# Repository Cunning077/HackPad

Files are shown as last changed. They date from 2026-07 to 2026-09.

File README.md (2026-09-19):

# Oled Display Hackpad

A differing design hackpad allowing customization at a cost effective way, complete with an advanced event handler and a system that makes use of computer hardware to perform complicated tasks on a budget microcontroller.

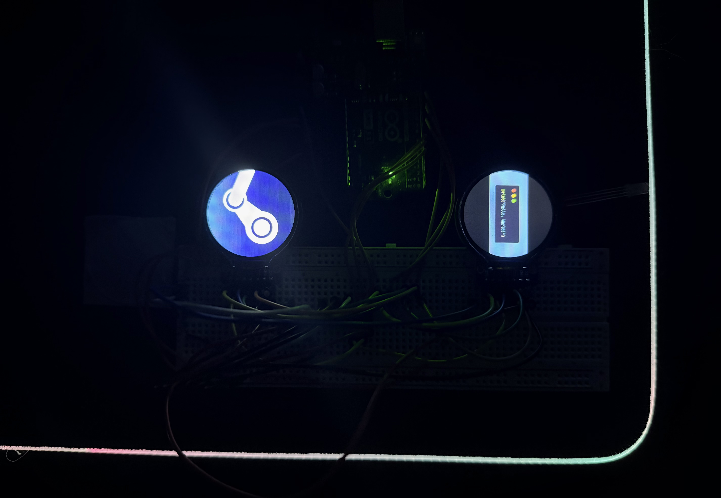
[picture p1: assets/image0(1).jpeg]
Prototype Screens


## Features

 - 1.28 " TFT Display (no specified number)
 - Customizable Macro Keys
 - Plug And Play USB Communication
 - User-Expandable Actions 

## Cad
The hackpad comes in 3 pieces, the PCB, the top case, and the bottom, the pcb is fastened into the bottom through 5 rectangular blocks that screw into the sides of the bottom section case, the top and bottom are fastened together with 4 screws.
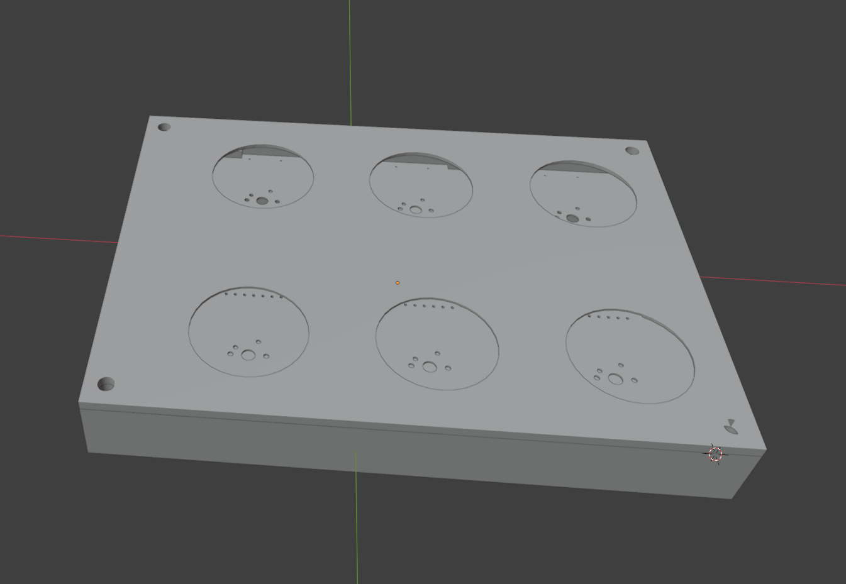
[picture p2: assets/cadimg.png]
Cad Image

(No current design for the case as in cosmetic look, if its popular maybe i will do one)

## PCB
Pcb made in kicad
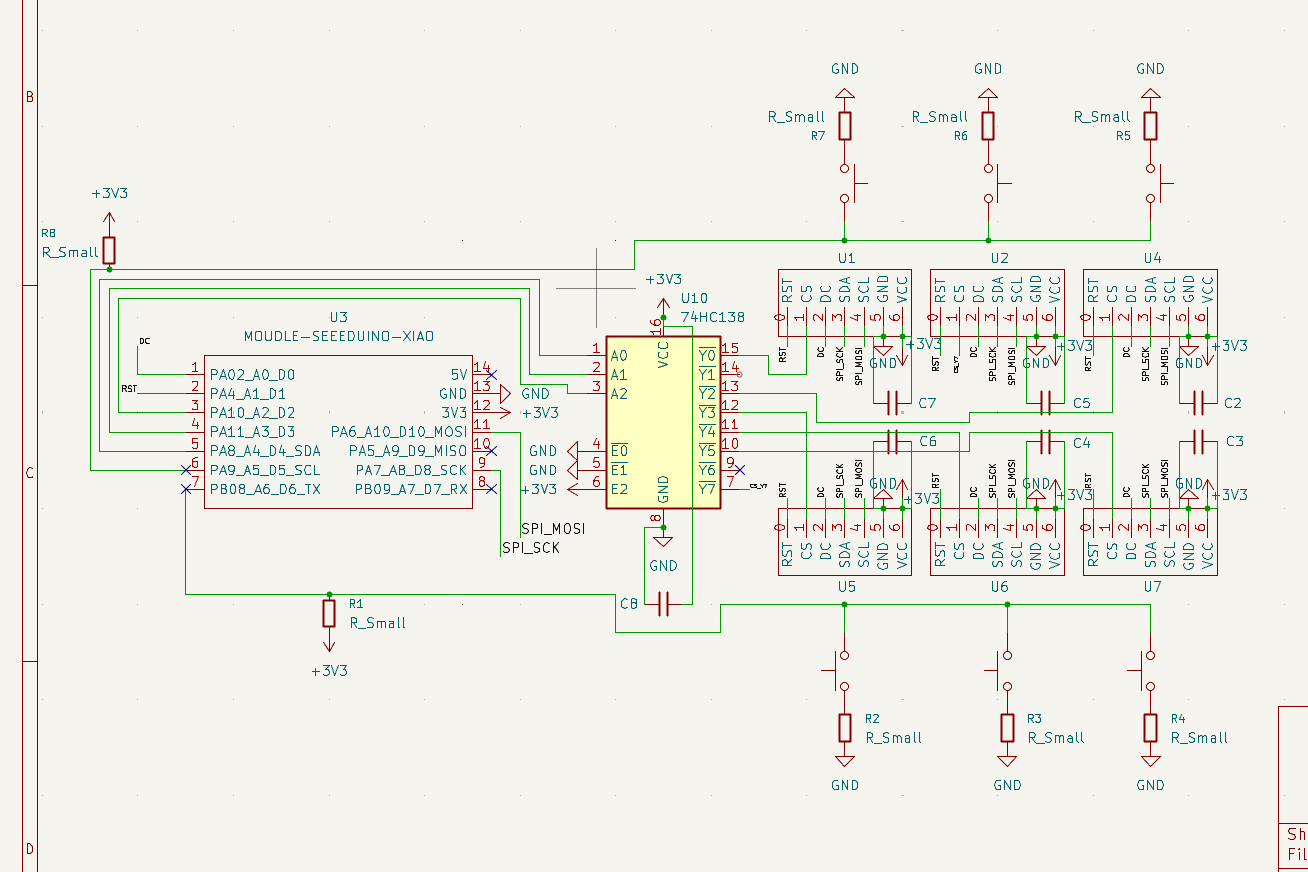
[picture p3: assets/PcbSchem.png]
Schematic

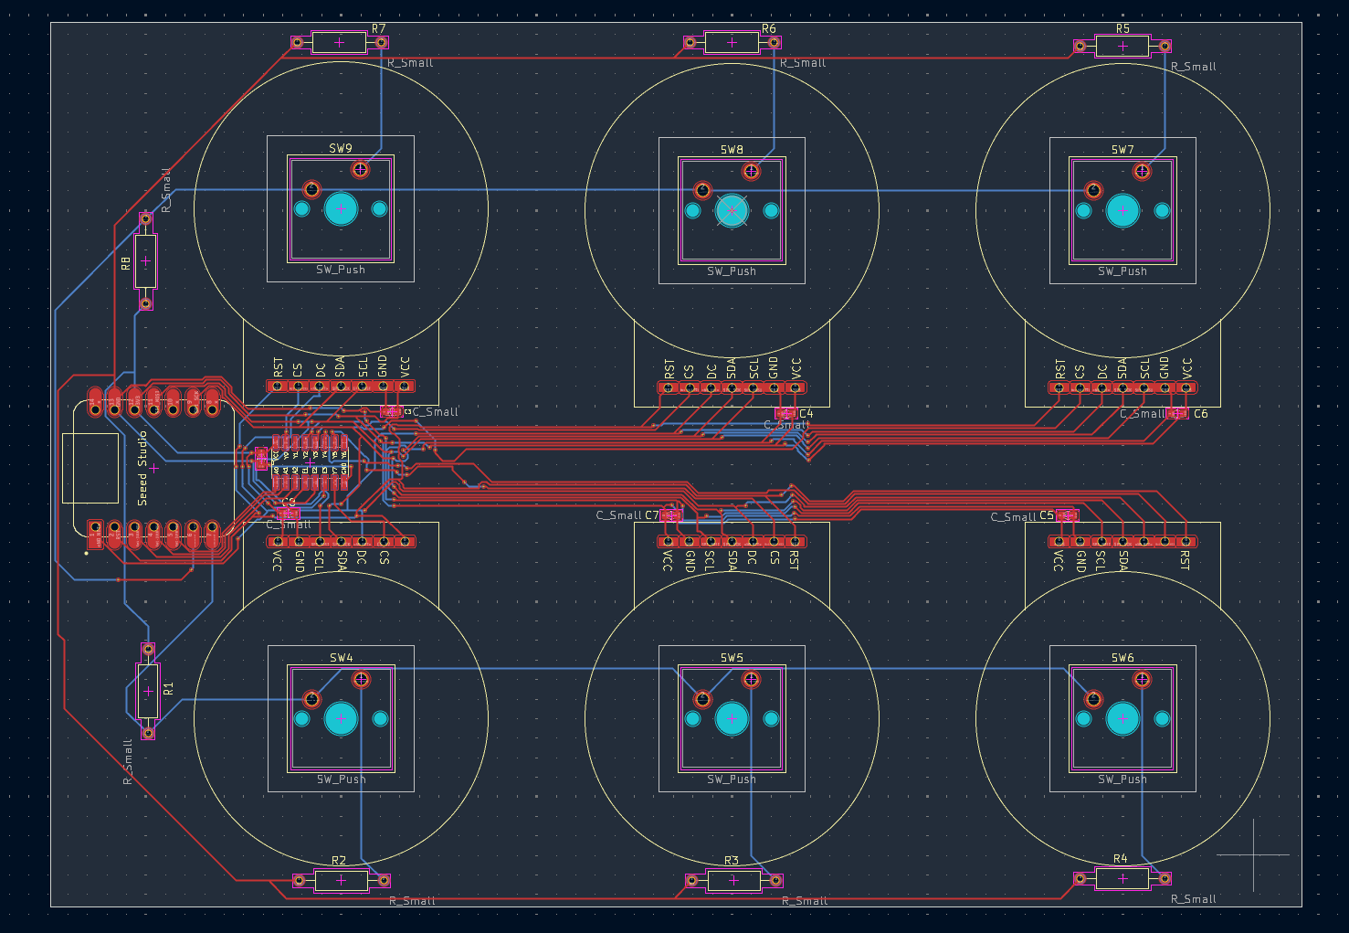
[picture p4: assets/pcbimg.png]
Pcb Image


## Firmware + Software
Software is broken down into the macro boards logic and the communication/event handler on the pc side. To get both simply clone this git hub repo, install platformio, and run the upload command for the arduinos logic. While the pc is abit trickier depending on what operating system you use. For Linux mint simply set the deamon/service.py as a startup service, it will simply run in the background searching for the macro board. The deamon is designed to simply run of that single service file, later on if this is popular i will add contribution info and other important stuff to allow others to more deeply control the board.

## BOM

 - 6 Cherry MX Switch
 - 6 1.28" TFT Displays
 -  4 * 4.5mm outer diameter 6mm depth heat inserts
 -  5 * 4.5mm outer diameter 4 mm depth heat inserts
 -  Screws that match (i got hundreds idk the name)
 - 2 sets of 3 differing resistors
 - 74HC138 circuit board
 - Microcontroller of choice 
 - 2 printed parts + 5 rectangular bits

|  Part| Price | Quantity |
|--|--|--|
|XIAO Seed Studio|$5.40|1|
|1.28 TFT Display|$6.00|6|
|4.5mm outer 6mm depth heat insert| $0.03|4|
|4.5mm outer 4mm depth heat insert|$0.03|5|
|Resistor set|$10.00|1|
|74HC138 circuit|$3.00|1|
|Cherry MX Switch|$0.5|6|
|Total|$48.67|Null|

See https://stardance.hackclub.com/projects/10218/devlogs/11779 for a detailed construction of the circuit on a bread board.

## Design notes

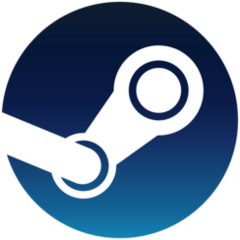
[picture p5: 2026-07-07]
deamon/images/DISP0_IMG.png

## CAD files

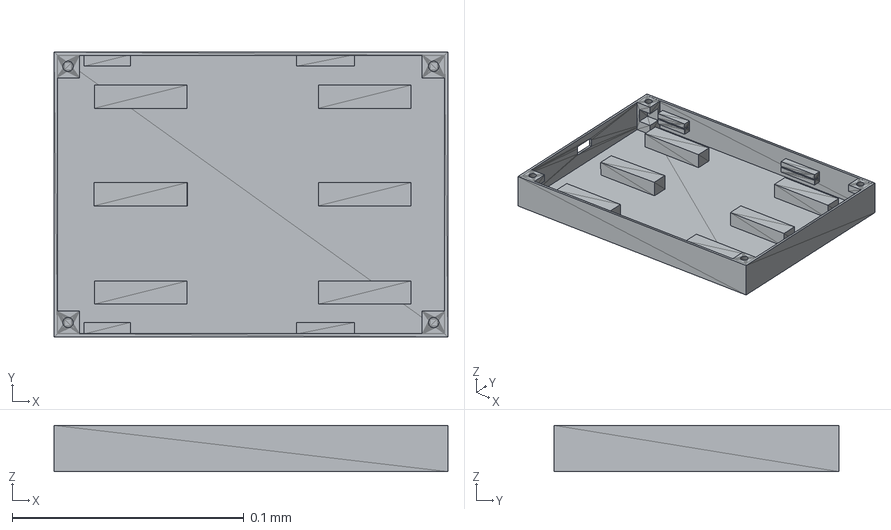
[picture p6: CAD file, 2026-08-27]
cad/hcase_bott.step
0.17 x 0.123 x 0.02 mm

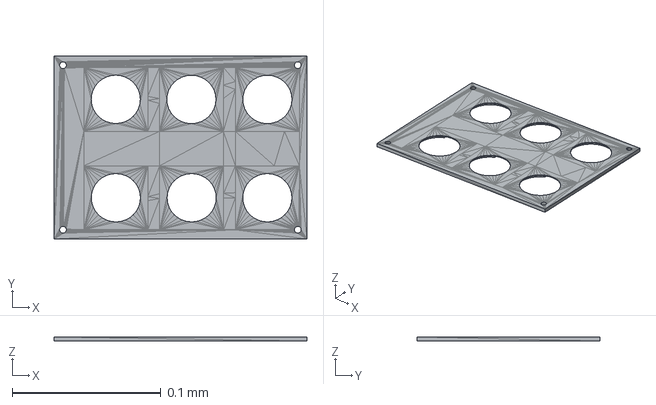
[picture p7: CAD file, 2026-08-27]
cad/hcase_top.step
0.17 x 0.123 x 0.003 mm

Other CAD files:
cad/hcase_PcbInc.blend
cad/hcase_bott.blend
cad/hcase_bott.stl
cad/hcase_top.blend
cad/hcase_top.stl

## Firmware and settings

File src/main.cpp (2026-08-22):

#include <Arduino.h>
#include <SPI.h>
#include <Adafruit_GC9A01A.h>
#include "display.h"
#include "cmdLedger.h"
#include "receiver.h"
#include "debugger.h"
#include "queue.h"
#include "buttons.h"


#define TFT_DC 9
#define TFT_RST -1
#define TFT_CS 10
#define LED_R 4
#define LED_G 3
#define LED_B 2

Adafruit_GC9A01A tft(TFT_CS, TFT_DC, TFT_RST);

void setup() {
   Serial.begin(115200);
   initDebugger(LED_R, LED_G, LED_B);
   initSelPin();
   initDisplay(2);
   initDisplay(0);
}

void loop() {
    readButtons();
    resolveConnection();
    readButtons();


    Packet packet;
    if (receivePacket(packet)) {
        switch (packet.command) {
            case CMD_HANDSHAKE:
                serialState = SerialBusy;
                readButtons();
                sendHandshake();
                return;

        }
        if (connectionState == CONNECTED) {
            setColor(1,1,0);
            Queue.push(packet);
            Serial.write(packet.command);
            readButtons();
            delay(1);
        }
    }

    if (connectionState == CONNECTED) {
        if (!Queue.empty()) {
            if (Queue.pop(packet)) {
                readButtons();
                resolveCMD(packet.command, packet.cmdId);
            }
        }
    }
}

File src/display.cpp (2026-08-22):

#include <display.h>
#include <Arduino.h>
#include "receiver.h"
#include "debugger.h"
#include "buttons.h"

#define SEL_A 7
#define SEL_B 6
#define SEL_C 5

void initSelPin() {
    pinMode(SEL_A, OUTPUT);
    pinMode(SEL_B, OUTPUT);
    pinMode(SEL_C, OUTPUT);
}

void initDisplay(int displayNum) {
    selectDisplay(displayNum);
    tft.begin();
    tft.setRotation(1);
}

void selectDisplay(uint8_t display) {
    digitalWrite(SEL_A, display & 0x01);
    digitalWrite(SEL_B, (display >> 1) & 0x01);
    digitalWrite(SEL_C, (display >> 2) & 0x01);
    delay(1);
}

void receiveImage() {
    delay(100);
    if (!waitForPayload(4)) {
        return;
    }
    uint8_t display = Serial.read();
    uint8_t width = Serial.read();
    uint8_t height = Serial.read();
    uint8_t rotation = Serial.read();
    uint32_t expectedPixels = (uint32_t)width * height;
    uint32_t bytesToRead = expectedPixels * 2;
    selectDisplay(display);  
    int16_t x = (240 - width) / 2;
    int16_t y = (240 - height) / 2;
    tft.setRotation(rotation);
    tft.startWrite();
    tft.setAddrWindow(x, y, width, height);
    uint8_t buffer[48];
    uint32_t bytesConsumed = 0;
    readButtons();
    while (bytesToRead > 0) {
        readButtons();
        uint16_t chunk = min(bytesToRead, sizeof(buffer));
        if (!waitForPayload(chunk)) {
            tft.endWrite();
            return;
        }
        Serial.readBytes((char*)buffer, chunk);
        readButtons();
        for (uint16_t i = 0; i < chunk; i +=2) {
            readButtons();
            uint16_t pixel = (buffer[i] << 8) | buffer[i + 1];
            bytesConsumed += 2;
            tft.writeColor(pixel, 1);
        }
        bytesToRead -= chunk;
    }
    tft.endWrite();
    setColor(1,1,1);
    readButtons();

}

void clearDisplay() {
    if (!waitForPayload(1))
        return;
    uint8_t display = Serial.read();
    selectDisplay(display);
    tft.fillScreen(GC9A01A_BLACK);
}

void displayText() {
    if (!waitForPayload(4))
        return;
    uint8_t display = Serial.read();
    uint8_t x = Serial.read();
    uint8_t y = Serial.read();
    uint16_t textLength = Serial.read();
        char text[128];
    if (textLength >= sizeof(text))
        textLength = sizeof(text) - 1;
    if (!waitForPayload(textLength)) {
        Serial.println("Text failed to retrieve");
        flushPayload(textLength);
        return;
    }
    Serial.readBytes(text, textLength);
    text[textLength] = '\0';
    selectDisplay(display);
    Serial.println(text);
    tft.setTextColor(GC9A01A_WHITE);
    tft.setCursor(x, y);
    tft.setTextSize(2);
    tft.print(text);
}


void displayTest() {
    if (!waitForPayload(1))
        return;
    uint8_t display = Serial.read();
    setColor(1,1,1);
    selectDisplay(display);
    for (int i = 0; i < 5; i++) {
        tft.fillScreen(GC9A01A_RED);
        tft.setTextColor(GC9A01A_WHITE);
        delay(1000);
        tft.fillScreen(GC9A01A_BLUE);
        delay(1000);
        tft.fillScreen(GC9A01A_GREEN);
        delay(1000);
        tft.fillScreen(GC9A01A_YELLOW);
        delay(1000);
    }
    
}

void displayFillScreen() {
    if (!waitForPayload(3))
        return;
    uint8_t display = Serial.read();
    uint16_t color = (Serial.read() << 8);
    color |= Serial.read();
    selectDisplay(display);
    tft.fillScreen(color);
}

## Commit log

2026-07-02 CMD Ledger + Controls
2026-08-20 Final Commit
    [Hackpad-B_Cu.gbr, Hackpad-B_Mask.gbr, Hackpad-B_Paste.gbr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]
2026-08-22 Project Adjustments + Buttons
2026-08-22 Project Adjustments + Buttons (1)
2026-08-22 Project Adjustments + Buttons (2)
2026-08-27 Bom.csv added
    [BOM.csv]
2026-08-27 added .step
    [hcase_bott.step, hcase_top.step]
2026-08-27 update bom
    [BOM.csv]
